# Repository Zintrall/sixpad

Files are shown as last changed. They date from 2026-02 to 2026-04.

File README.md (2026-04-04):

# sixpad
Sixpad is a simple macropad with six switches, rotary encoder and a OLED display

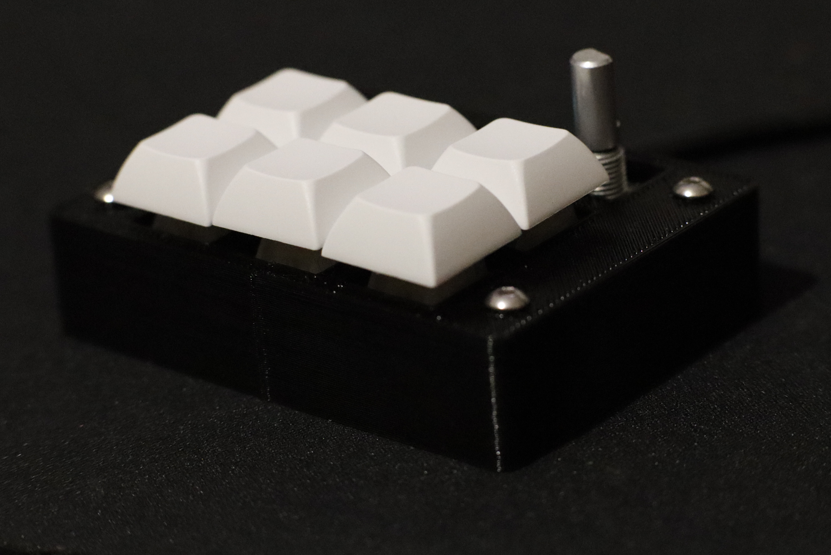
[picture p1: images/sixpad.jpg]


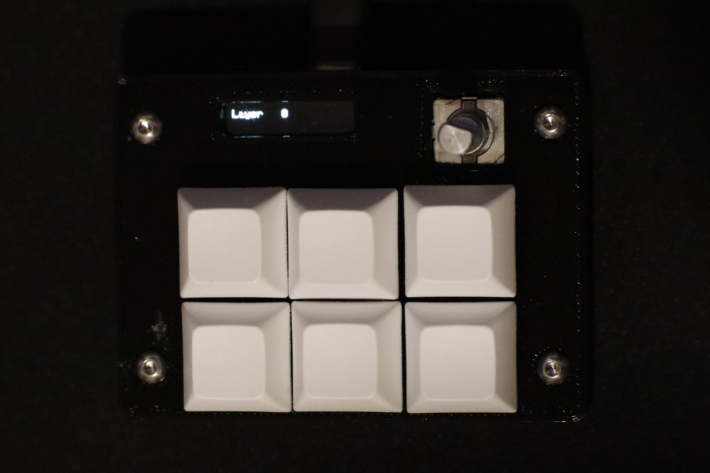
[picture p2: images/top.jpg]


## Features
- 128x32 OLED Display
- EC11 Rotary encoder
- 6 Keys
- RP2040
- VIAL support

## PCB
- designed using KiCAD

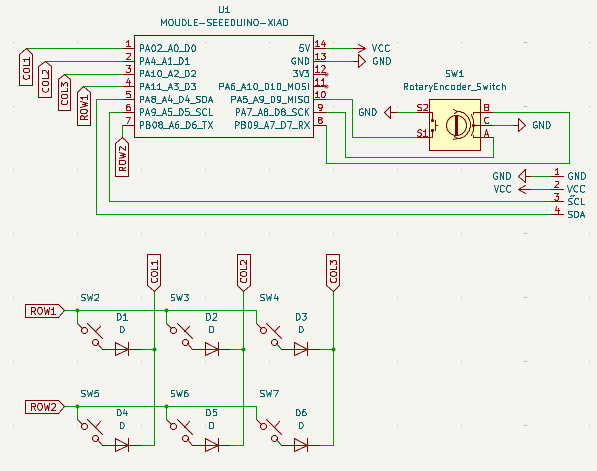
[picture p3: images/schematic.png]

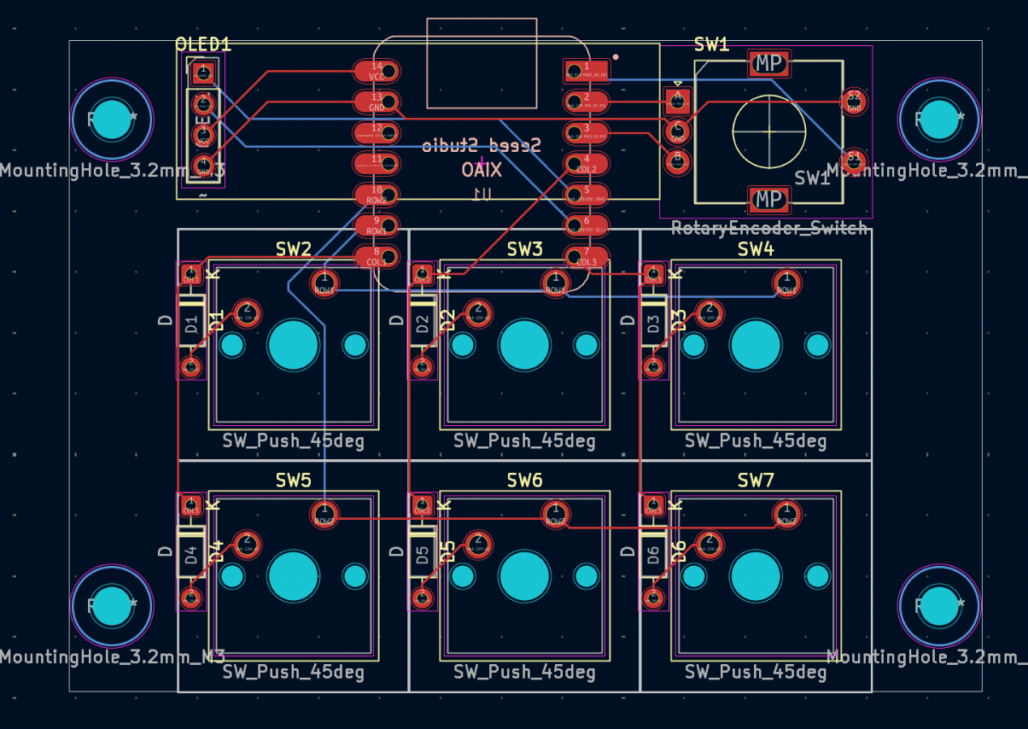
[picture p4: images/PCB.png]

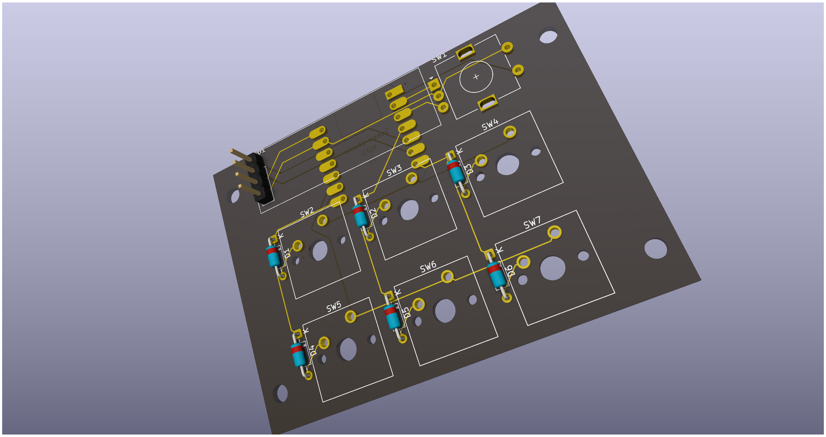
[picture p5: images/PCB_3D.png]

## Case
- designed using openSCAD

The case is only one part, as the PCB will be put in place through the bottom hole and held there by 4x M3 nuts and screws.

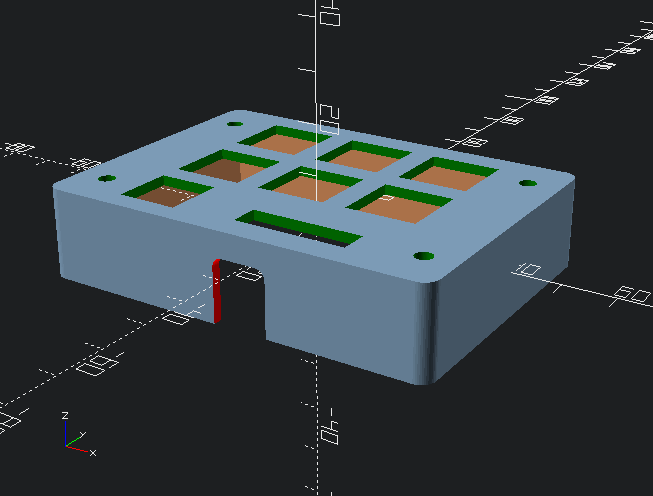
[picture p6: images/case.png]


## Firmware
- uses QMK firmware
- supports vial (even rotary encoder)
- OLED display displays what layer you are on

## BOM
- 6x Cherry MX Switches
- 6x DSA Keycaps
- 4x M3x16mm SHCS Bolts
- 4x M3 Nuts
- 6x 1N4148 DO-35 Diodes.
- 1x 0.91" 128x32 OLED Display
- 1x EC11 Rotary Encoder
- 1x XIAO RP2040
- 1x Case

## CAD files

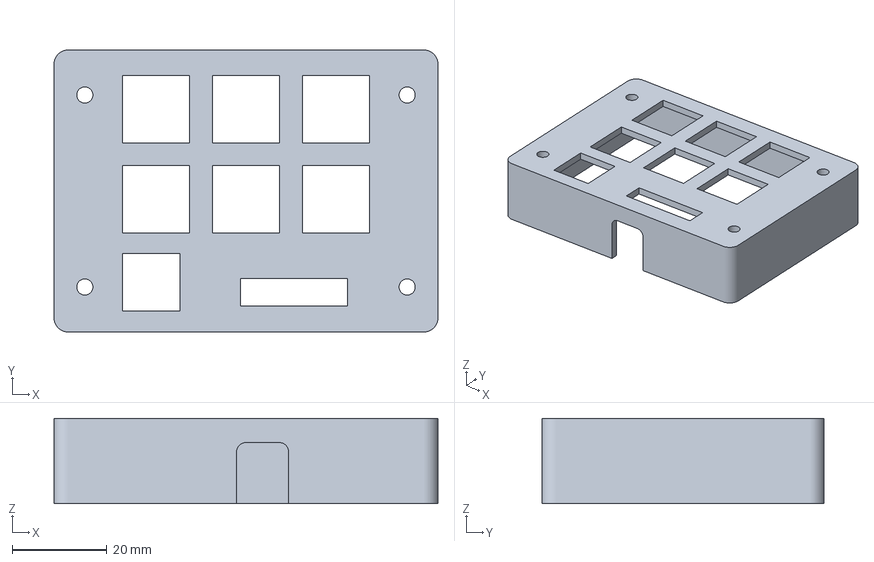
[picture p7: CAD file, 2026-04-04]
CAD/case.3mf
81.0 x 59.5 x 18.0 mm

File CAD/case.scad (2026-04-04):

use <smooth_prim.scad>

$fn=50;

board_extra_size = 1;
board_height = 14;
board_width = board_extra_size*2+53.5;
board_length = board_extra_size*2+75;
case_extra_width = 4; // the side width will be the half of this value
keycap_length = 19;
switches_box_length = 14.2;
encoder_box_length = 12.2;
display_box = [22.6,5.8,20];
usb_c = [11,16.5,case_extra_width];


difference() {
    translate([-(board_length+case_extra_width)/2,-(board_width+case_extra_width)/2,-((board_height+case_extra_width)/2)]) {
    SmoothXYCube([board_length+case_extra_width,board_width+case_extra_width,board_height+case_extra_width],3);
    };
    translate([0,0,-case_extra_width/2]){
    cube([board_length,board_width,board_height+case_extra_width],center = true);}
    color("green"){
    for (x = [-1:2:1]){
        for (y = [-1:2:1]) {
            translate([((board_length/2)-3.5-board_extra_size)*x,((board_width/2)-6.5-board_extra_size)*y,0]){
                cylinder(h=board_height+case_extra_width*2+1,d=3.4,center=true);
    }}}
    translate([0,(board_width/2 - board_extra_size)-keycap_length,0]){
    union(){
    for (x = [-1:1]){
        for (y = [-1:2:1]) {
            translate([keycap_length*x,(keycap_length/2)*y,0]){
                cube([switches_box_length,switches_box_length,board_height+case_extra_width*2+1],center=true);
    }}}}}
    translate([-(board_length/2 - 17.5 - board_extra_size),-((board_width/2)-7.5 - board_extra_size),0]){
    cube([encoder_box_length,encoder_box_length,board_height+case_extra_width*2+1],center=true);
    }
    translate([(board_length/2 - 16.1 - board_extra_size - display_box[0]/2),-(board_width/2-display_box[1]/2-2.5-board_extra_size),0]){
    cube(display_box,center=true);
    }
    }
    color("red"){
    translate([board_length/2-29.5-board_extra_size,-board_width/2,board_height/2+(case_extra_width/2)-20.1]){
    rotate([90,0,180]){
    translate([-1,-1.5,-case_extra_width/2]){
    SmoothXYCube(usb_c,2){}}}}}
}

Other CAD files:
production/case.stl

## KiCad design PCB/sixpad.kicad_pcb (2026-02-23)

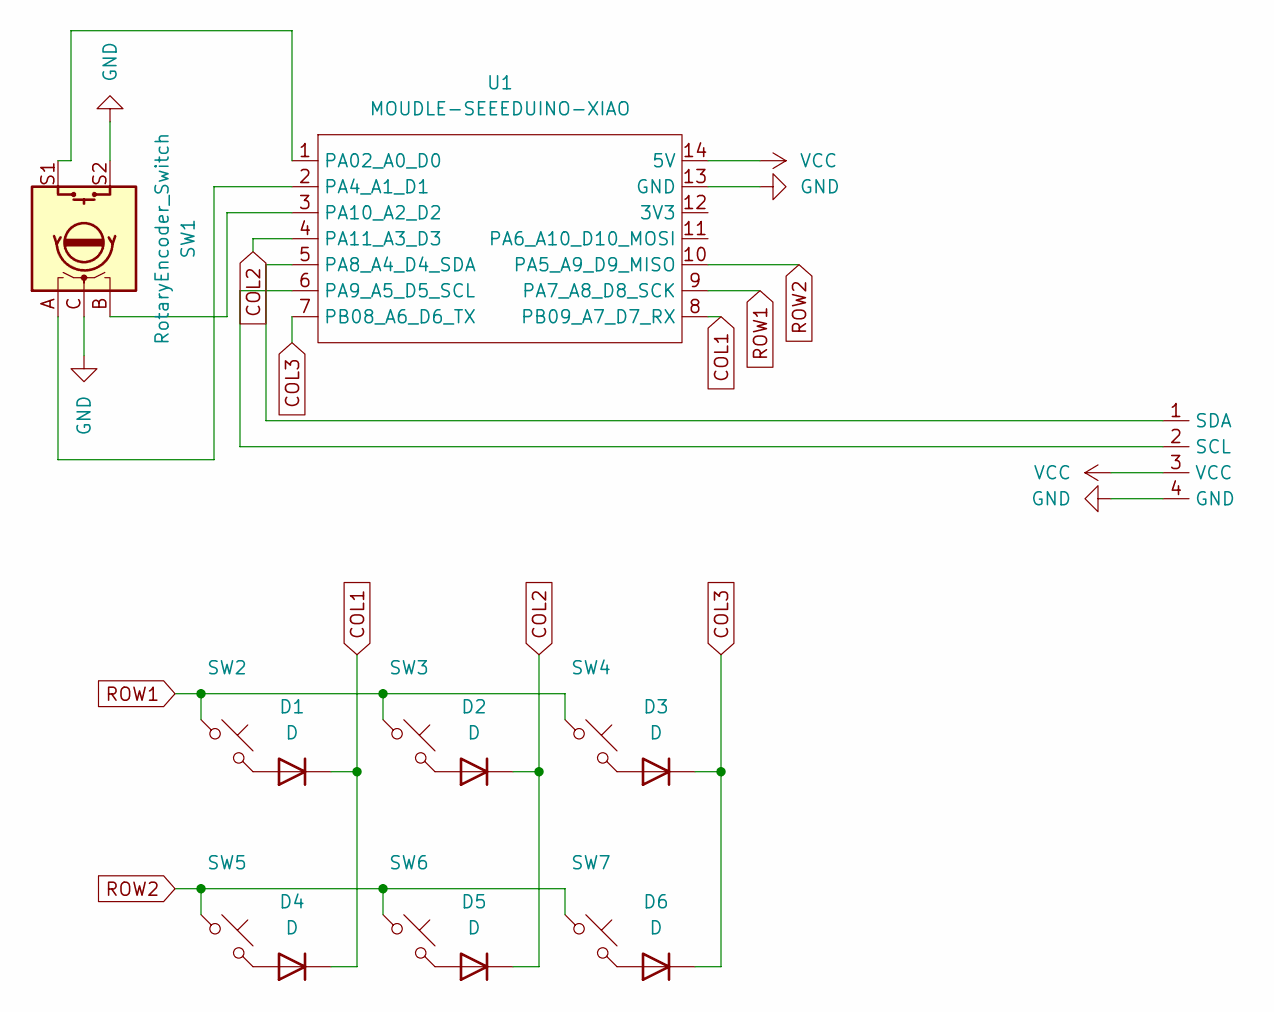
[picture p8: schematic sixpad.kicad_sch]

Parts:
D1, D2, D3, D4, D5, D6: D; D_DO-35_SOD27_P7.62mm_Horizontal
OLED1: PinHeader_1x04_P2.54mm_Vertical
SW1: RotaryEncoder_Switch; RotaryEncoder_Alps_EC11E-Switch_Vertical_H20mm
SW2, SW3, SW4, SW5, SW6, SW7: SW_Push_45deg; SW_Cherry_MX_1.00u_PCB
U1: MOUDLE-SEEEDUINO-XIAO; XIAO-Generic-Hybrid-14P-2.54-21X17.8MM

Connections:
COL1: D1.1 (K), D4.1 (K), U1.8 (PB09_A7_D7_RX)
COL2: D2.1 (K), D5.1 (K), U1.4 (PA11_A3_D3)
COL3: D3.1 (K), D6.1 (K), U1.7 (PB08_A6_D6_TX)
GND: OLED1.4 (GND), SW1.C, SW1.S2, U1.13 (GND)
unnamed: D1.2 (A), SW2.2
unnamed: D2.2 (A), SW3.2
unnamed: D3.2 (A), SW4.2
unnamed: D4.2 (A), SW5.2
unnamed: D5.2 (A), SW6.2
unnamed: D6.2 (A), SW7.2
unnamed: OLED1.2 (SCL), U1.6 (PA9_A5_D5_SCL)
unnamed: OLED1.1 (SDA), U1.5 (PA8_A4_D4_SDA)
unnamed: SW1.S1, U1.1 (PA02_A0_D0)
unnamed: SW1.A, U1.2 (PA4_A1_D1)
unnamed: SW1.B, U1.3 (PA10_A2_D2)
ROW1: SW2.1, SW3.1, SW4.1, U1.9 (PA7_A8_D8_SCK)
ROW2: SW5.1, SW6.1, SW7.1, U1.10 (PA5_A9_D9_MISO)
VCC: OLED1.3 (VCC), U1.14 (5V)

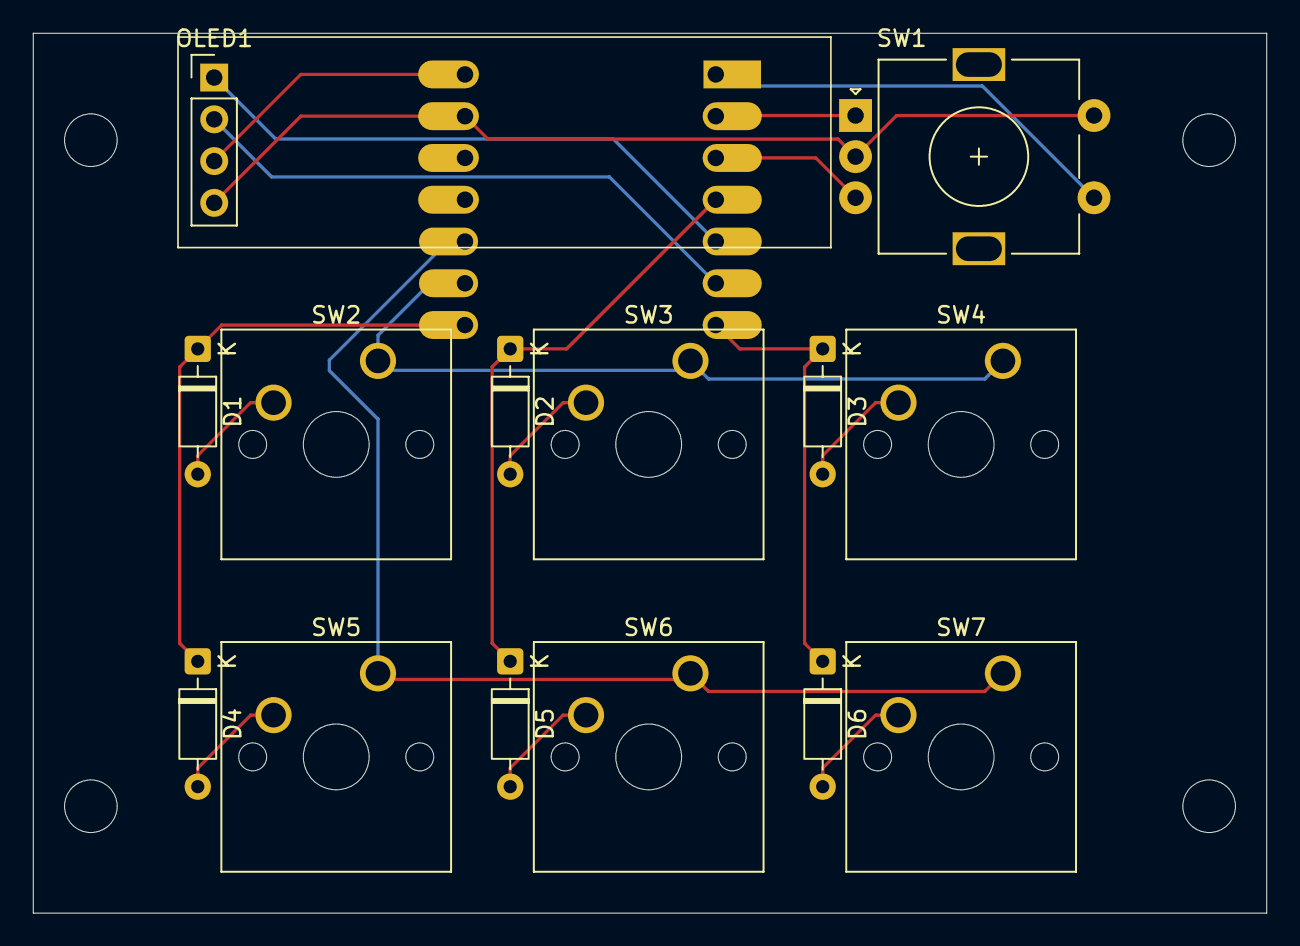
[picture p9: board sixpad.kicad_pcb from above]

Board: 2 copper layers, 75.0 x 53.5 mm, 15 parts (1 on the bottom side), 18 nets.

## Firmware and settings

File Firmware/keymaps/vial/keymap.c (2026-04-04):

// Copyright 2024 zin
// SPDX-License-Identifier: GPL-2.0-or-later

#include QMK_KEYBOARD_H

// Define the layers
enum layer_names {
    _BASE,
    _LAYER1,
    _LAYER2,
    _LAYER3
};

bool oled_task_user(void) {
    oled_write_P(PSTR("Layer "), false);

    oled_write(get_u8_str(get_highest_layer(default_layer_state), ' '), false);

    return false;
}


const uint16_t PROGMEM encoder_map[][NUM_ENCODERS][NUM_DIRECTIONS] = {
    [_BASE]   = { ENCODER_CCW_CW(KC_AUDIO_VOL_UP, KC_AUDIO_VOL_DOWN) },
    [_LAYER1] = { ENCODER_CCW_CW(KC_TRNS, KC_TRNS) },
    [_LAYER2] = { ENCODER_CCW_CW(KC_TRNS, KC_TRNS) },
    [_LAYER3] = { ENCODER_CCW_CW(KC_TRNS, KC_TRNS) }
};

const uint16_t PROGMEM keymaps[][MATRIX_ROWS][MATRIX_COLS] = {
    [_BASE] = LAYOUT(
        KC_7, KC_8, DF(3),
        KC_4, KC_5, KC_6
    ),
    [_LAYER1] = LAYOUT(
        KC_A, KC_B, DF(3),
        KC_C, KC_D, KC_E
    ),
    [_LAYER2] = LAYOUT(
        KC_X, KC_Y, DF(3),
        KC_Z, KC_R, KC_D
    ),
    [_LAYER3] = LAYOUT(
        DF(0), DF(1), DF(2),
        KC_TRNS, KC_TRNS, KC_TRNS
    )
};

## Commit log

2026-02-23 Project upload
    [case.3mf, case.scad, case.stl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]
2026-02-24 Fixed the PCB image so it shows up
2026-02-24 renamed pcb.png
2026-02-24 added 3D PCB image
2026-03-11 updated 3D models
    [full_model(low_quality_board).3mf, tinker.obj]
2026-04-04 resized usb-c case slot
    [case.3mf, case.scad, case.stl]
